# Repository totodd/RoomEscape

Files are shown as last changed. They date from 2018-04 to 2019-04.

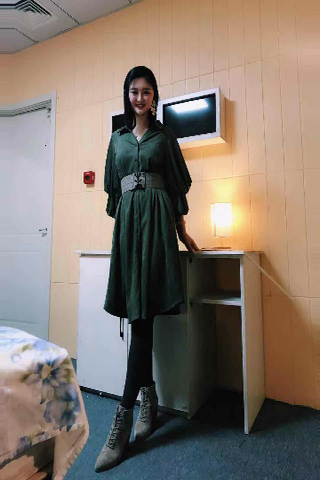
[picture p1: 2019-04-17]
module/Daniel/newPhone/色盲1/72.bmp

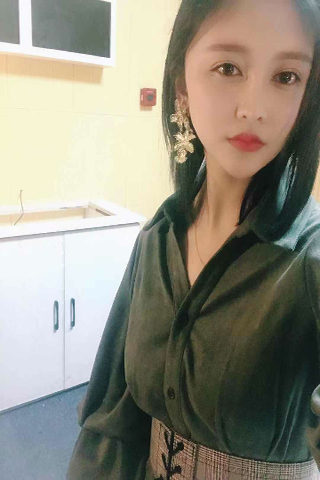
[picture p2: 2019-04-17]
module/Daniel/newPhone/色盲1/73.bmp

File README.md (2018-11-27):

# RoomEscape
room escape functions

[脉搏模块]
input:

inner connections:
  black: GND
  blue: input = LOW
  yellow: no display if LOW

[5分钟倒计时模块]

input:
  1. signal
  2. GND
  -. button
  3. power cable

functions:
    [initial:]
      all displaying zero
    [action:]
      if(signal || button)
        counter start from 5 mins

output:
  1. signal: HIGH when counting is over
  2. GND

inner connections:
  1. black: GND
  2. green: start signal = LOW
  3. yellow: reset signal = LOW
  4. red: 5V output
  5. white: signal when count down = LOW

[指纹模块]
input:
  -. button
  1. power cable

functions:
  [initial: ]
    if(fingerprint saved) scanning fingerprint
    else waiting for saving fingerprint
  [action:]
    if(button)
      clean all saved fingerprint, start waiting

    when setting fingerPrint:
      scan the fingerprint twice, when no light is flashing, setting is successful.
        (can only save one fingerprint)

output:
  1. signal = HIGH
  2. GND

[IC卡单卡模块]
input:

output:
  1. output signal = HIGH
  2. 5v vin
  3. GND
  4. GND
  5. SDA
  6. SCL

[IC总控]
input:
  1. power cable
  -. switch
  -. button

functions:
  - press button to add connected devices
  - pull switch to choose sequence mode or all-in mode

output:
  1. NOUT signal = LOW
  2. GND
  3. --
  4. GND
  5. GND
  6. OUT signal = HIGH

[电子琴]
input:

[抖音10s模块]
input:
  -. button
  1. power cable 12v
  2.

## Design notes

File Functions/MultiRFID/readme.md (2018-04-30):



 * Typical pin layout used:
 * -----------------------------------------------------------------------------------------
 *             MFRC522      Arduino       Arduino   Arduino    Arduino          Arduino
 *             Reader/PCD   Uno/101       Mega      Nano v3    Leonardo/Micro   Pro Micro
 * Signal      Pin          Pin           Pin       Pin        Pin              Pin
 * -----------------------------------------------------------------------------------------
 * RST/Reset   RST          9             5         D9         RESET/ICSP-5     RST
 * SPI SS 1    SDA(SS)      ** custom, take a unused pin, only HIGH/LOW required **
 * SPI SS 2    SDA(SS)      ** custom, take a unused pin, only HIGH/LOW required **
 * SPI MOSI    MOSI         11 / ICSP-4   51        D11        ICSP-4           16
 * SPI MISO    MISO         12 / ICSP-1   50        D12        ICSP-1           14
 * SPI SCK     SCK          13 / ICSP-3   52        D13        ICSP-3           15

in this application

Pin arrangement:

SS1 -> Pin 10
SS2 -> Pin 8
indicater1 -> Pin 2
indicater2 -> Pin 3
output -> Pin 4
reset -> Pin 5

variables:

NR_OF_READERS 	-> number of readers 
ssPins 			-> reader list 				
targetSequence 	-> the truth sequence of tapping readers
passAction() 	-> action after getting correct sequence
failAction() 	-> action after getting wrong sequence

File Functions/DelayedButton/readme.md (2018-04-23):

This foundamental function is used to design a delayed button input so that after a required time pressed, a control signal will be sent to control external devices, such as: Control lights on/off.  Locker open/close.

parameters declearation:

      Input:
      
            button :         Button Input Signal     
            Reset:           Highest external control
            
      Output:
      
            OutputSignal:    Output Controled signal (connect to LED or Locker or Relay)
            CurrentState:    Current state indicator, HIGH means WORKING, LOW means IDEL
            
      Variables:
        
            debounceDelay:    The amount of time to delay (second)

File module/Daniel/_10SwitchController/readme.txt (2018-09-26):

10 switches module

features:

reset pin

when pin match, output a high signal

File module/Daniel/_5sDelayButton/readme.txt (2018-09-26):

This is the 5 seconds delayed button, when button is pressed 5 seconds, will output a high signal

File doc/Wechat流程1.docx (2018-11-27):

流程:

遥控器：只连接主控，主控连接其他所有继电器/sensor

玩家被指引进黑暗房间，NPC触发一个视频（A1）【暂不开发】。视频播放后，照明灯亮起（A4）【有一个继电器模块管所有照明灯，暂定手动开所有】。NPC进入房间开场白。并指引玩家进入各个房间（A2）【一个遥控器，上面有十个按钮，分别对应五个门的上锁/解锁。继电器模块，逻辑模块，主控】，一切妥当后，NPC触发开启童谣模式（A3）【一个遥控器，控制开始播放，播放时，按照顺序播放闪电和童谣。音频模块，闪电灯模块，主控】并伴随闪电。第一次闪电后房间停电（A4）【继电器模块，主控】，断开房间1-8的照明，1-3的门。无线电通话应答器播放语音（A5）【由主控发起信号决定播放音频，音频模块，主控】，玩家可以使用手摇发电机（A4）【手摇发电机，继电器模块，测量模块，主控】，恢复电力。

以下为并行：（*）

*玩家可以在酒窖内找到3瓶酒放置正确位置（A6）【3点IC触控】，伸出推杆逃生。【电机模块】

*大厅玩家可以按住地图上1点，开启灯。（A7）【单点延时按钮模块】

*大厅玩家在日历上按住2点，开灯2（A7）【双点延时按钮模块】

*大厅玩家放置正确物品，开灯3（A7）【单点IC触控】

*大厅玩家按照琴谱弹奏，开灯3。 得到钥匙1（A7）【撞击模块，顺序模块】

*画室玩家放置正确物品开锁（A8）【ic触控，顺序模块】，玩家为4个物品挑选颜色（A8）【旋钮顺序开关】，开锁【电机模块】。得要钥匙2

*娱乐室玩家可以摆放3点飞镖（A9）【磁力模块】和6点的台球（A9）【红外模块】，得到钥匙3【电机模块】

在此期间内，NPC可以进入房间内，遥控断掉房间内1-8照明灯，亮起1-4警示灯（A4）。并播放一段音频（A3）。NPC走后，可以恢复照明至原来的效果（A4），并停止播放音频（A3）。

玩家收集4把钥匙以后，同时插进钥匙孔【四点金属感应模块】，NPC会收到警报（A10）【无线警报模块】。引导玩家进入下一房间。

以下为多选1：（不冲突）

*玩家可以通过输入一个切断电源的密码（A11）【小键盘密码模块 主控】，切断房间内灯源、门，同时亮起警示灯（A4.A3）【灯光模块】，同时开锁，NPC进入与玩家互动。10min后开门。

*NPC主动进入房间，进入蓝色字体模式（A3.A4）【灯光模块】，玩家需要找到枪和子弹，组装后，用枪射杀NPC（A12）【暂定玩具枪】。NPC死的时候帮助玩家开门（A2）

*NPC主动帮玩家开门（A2）

总价：16500， 如果加蓝灯效果（记录游戏状态，加1500）.

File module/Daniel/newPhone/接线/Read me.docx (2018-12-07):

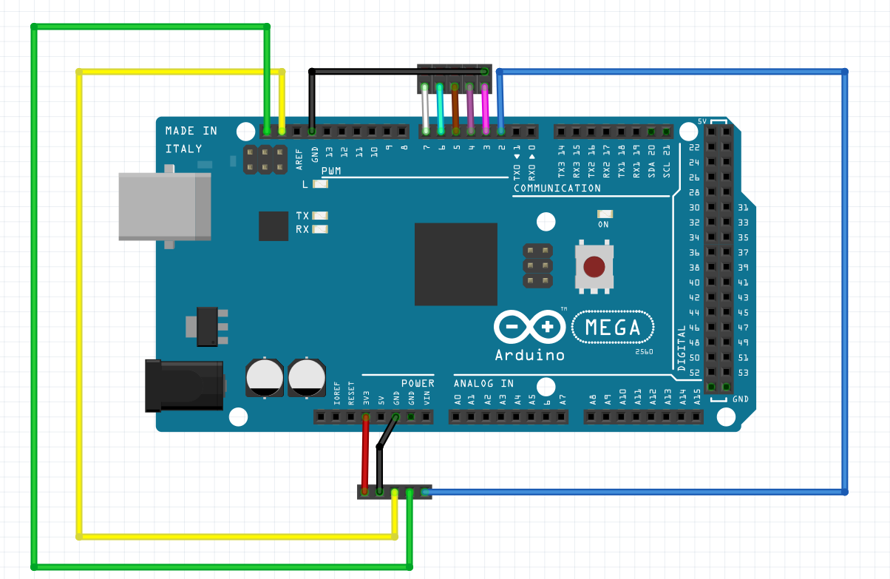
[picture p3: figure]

接线图下方的五条线，接好之后直接连接屏幕

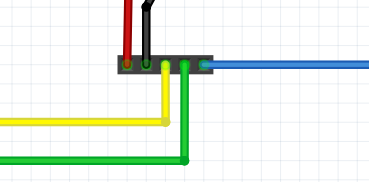
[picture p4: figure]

上方的：

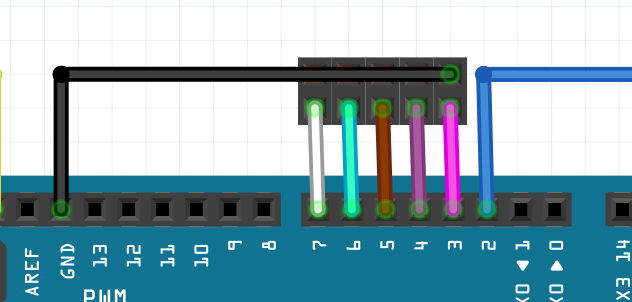
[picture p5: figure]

pin3： 定义为 INPUT，当A2的第四个音频播放完毕之后，输出HIGH到这里

pin4： 定义为 INPUT，当电话打完之后（电话音频播放完之后），输出HIGH到这里 （这个可以不用）

pin5： 定义为 OUTPUT， 连接MP3，这个输出HIGH的时候，播放电话音频文件

pin6： 定义为 OUTPUT， 连接MP3，这个输出HIGH的时候，播放开机音频文件

pin7： 定义为 OUTPUT， 连接MP3,这个输入HIGH的时候,播放电话来电响铃音频文件

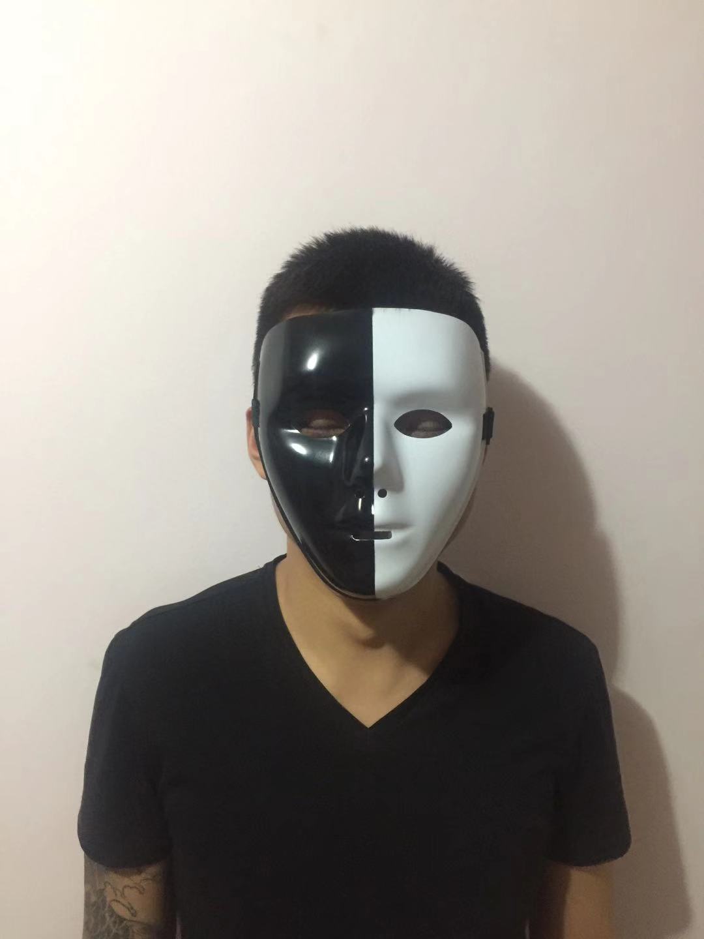
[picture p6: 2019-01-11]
module/faceRecog/15871544867203_.pic.jpg

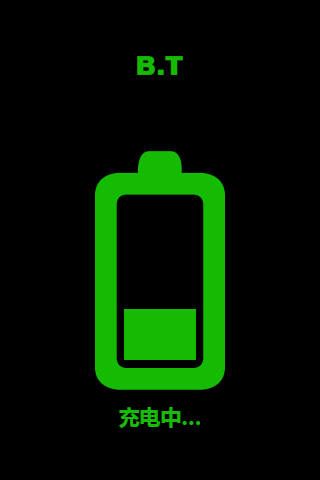
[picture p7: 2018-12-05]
module/Daniel/newPhone/色盲1/充电中1.bmp

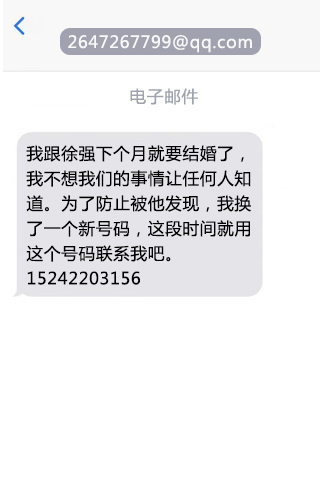
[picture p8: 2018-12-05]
module/Daniel/newPhone/色盲1/邮件界面.bmp

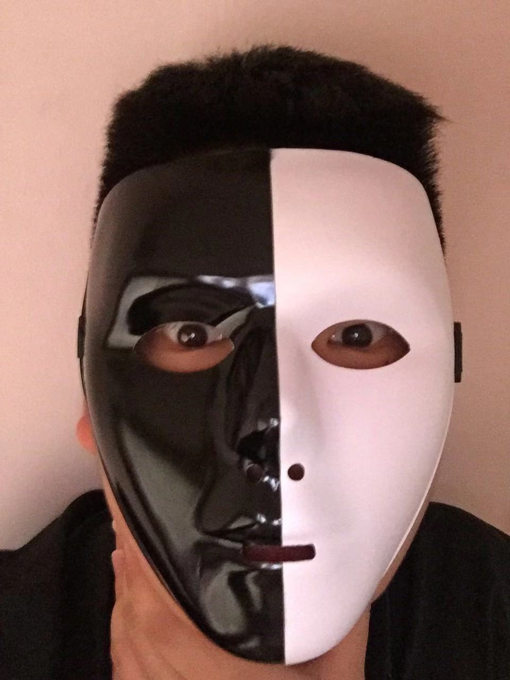
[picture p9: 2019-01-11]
module/faceRecog/15721544851673_.pic.jpg

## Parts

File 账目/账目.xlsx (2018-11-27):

 | 密室项目账单
 | 日期 | 名称 | 价格 | 总价 | 10777.49
 | 8.28 | 第一批材料 | 2568.34
 | 8.28 | 喷锡板 | 178 | 剩余 | 4222.51
 | 8.29 | MP3 解码 | 119.38
 | 8.29 | 对插线 | 159.8
 | 不记得了 | 衣服 | 500
 | 9.21 | Jaycar 电焊材料 | 122.75
 | 9.21 | bunnings 电焊 | 113.1
 | 9.26 | Jaycar | 149.75
 | 9.27 | Jaycar box | 105.5
 | 9.27 | bunnings 电钻 | 419.35
 | 9.27 | 第二批材料 | 739.97
 | 9.27 | MP5 | 283
 | 9.27 | vLCD | 239
 | 9.29 | 运费 | 152
 | 10.02 | 吃饭 | 370
 | 10.01 | 吃饭 | 197.5
 | 10.4 | PCB | 330
 | 不记得了 | Jaycar James | 155
 | 10.09 | tf卡 | 80
 | 10.09 | 话筒耳机 | 18
 | 10.09 | 开关 | 64
 | 10.11 | 第三批材料 | 313.2
 | 10.11 | arduino拓展板 | 61
 | 10.12 | 电线 | 32
 | 10.17 | Jaycar 盒子 | 165.25
 | 10.11 | Element14 | 157.85
 | 10.15 | Jaycar | 66.75
 | 10.12 | Jaycar 盒子 | 175
 | 10.16 | Kmart | 50
 | 10.15 | 运费 | 181
toto | 10.28 | pcb | 143
toto | 10.28 | 淘宝材料 | 12
toto | 10.28 | 淘宝材料 | 376
toto | 10.28 | 淘宝材料 | 63
toto | 10.28 | 淘宝材料 | 600
toto | 10.28 | 淘宝材料 | 194
toto | 10.28 | 淘宝材料 | 30
toto | 10.28 | 琴 | 311
toto | 10.28 | 计时 | 160
toto | 10.28 | 焊接工具 | 154
toto | 11.1 | 淘宝材料 | 214
toto | 11.1 | pcb | 188
toto | 11.1 | xh2.54 wire | 22
toto | 11.1 | 电烙铁 | 44

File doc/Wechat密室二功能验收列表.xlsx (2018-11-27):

基本模块编号 | 乙方提供 （数量待定） | 说明（要求与功能）
1 | 主控（顺序模块） | 用于连接不同模块，控制模块协同工作， 来完成特定功能，提供可手持遥控器
2 | 数码管计时器模块 | 5min倒计时
3 | 继电器模块 | 控制铁球落下，电磁门等设备
4 | 小键盘密码模块 | 输入密码控制控门继电器模块
5 | 指纹识别模块 | 识别甲方提供的指纹道具，触发 电子锁模块开锁
6 | 电子锁模块 | 有线，用于所有需要开锁的设备逻辑
7 | 虚拟机模块 | 用户输入制定日期，播放对应视频
8 | 10秒计时模块 | 模式一：演示模式，拍一下是0，再拍一下 是10. 模式二：玩家模式，拍一下是0，再拍一下 数到几就是几
9 | 四点IC模块 | IC卡接触读卡器之后触发
10 | 10点switch模块 | 十个switch分别有正负两种状态，其中四个拨到负状态，触发
 |  | 报价：16500

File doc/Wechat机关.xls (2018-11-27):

编号 | 名称 | 描述 | 备注
A1 | 进门视频 | NPC触发视频
A2 | 黑白牛马 | 4点IC卡，同时放置后触发开锁，播放音频
A3 | 对联机关 | 7点IC卡，同时放置开锁。音频。
A4 | 生辰八字 | 22位按钮，输入8位密码，播放音频，再输入8位密码，播放音频，开锁。
A5 | 拍婚照 | AR感应/IC卡+重力感应，识别后，闪光灯闪一下，开锁，音频。
A6 | 牌位 | 2点IC卡，开锁。

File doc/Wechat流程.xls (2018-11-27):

编号 | 名称 | 描述 | b备注
A1 | 无线接收 | 可以无线接受控制电话的响铃（第一次），2个房间门的通断。 | 一共4个音响，房间内的提示音；走廊的音效；电话；手机；
A2 | 电话机关 | 无线遥控响铃，摘机后播放语音1。按8888，A3播放不同画面。A4触发后，响铃摘机播放语音2.语音2播放完成后，房间1门打开（A1）。A3播放完视频3之后，响铃，播放语音3.通过拨打数字串，播放外卖语音，正确触发后，且房间1门关闭（需检测）播放视频4（A3），A3播放完录像4以后，响铃，播放录音4.拨打手机号，走廊音响响起，走廊音效和电话音效同步。 | 语音1234，可以通过按钮1234来重播。
A3 | 双视频 | 初始为黑屏待机画面，A2完成8888后，播放两个不同画面。A4完成后，播放两个画面。A5每个密码完成后会得到对应视频，其中走廊监控器为实时监控，两个画面都得到后，且房间1门关闭（需检测且吸合）会播放视频1.视频1播放完毕后按钮1触发，可以重播视频1，播放完毕回到红字状态。A6触发后，播放录像2，按钮2可以重播视频2，播放回到红字，且房间1门打开。A7触发接通电源1后，播放视频3，播放完毕后，房间1门开（A1）。按钮3可以重播录像3，完毕回到红字。A2外卖完毕后，且门关，播放视频4.播完后，A2电话响，视频播放视频5.A2触发电话号后，同步播放视频6，视频6结束后，断掉所有电源。 | 带音效，设置在走廊
A4 | 保险箱 | 小键盘输入7位密码，开锁。
A5 | 录像台 | 按下按钮，升起推杆。同时播放音频，用大键盘输入走廊和房间监控器编号，按钮可切换输入行，并可以重复触发语音。成功输入后。A3可以获得对应的视频，其中一个是实时监控。两个都成功输入后，播放语音。 | 走廊监控器编号 房间监控器编号
A6 | 5灯开关 | 酒店5灯开关，5个按顺序按下后，开锁。A3播放录像2.
A7 | 断电机关 | 磁力感应1（干簧管按钮）断掉电源1（继电器）播放音频。IC卡感应后，且房间1门关闭（需检测且吸合）后，接通电源1.A3视频6播放完毕后，断掉电源2.磁力感应2（再此之前不能触发），触发后开门。
A8 | 人脸识别 | A7断电之后，才能触发，但需要提前供电。触发后开锁。
A9 | 手机 | 游戏开始时，一直显示为充电中，A2播放完录音4后，开启开机步骤，且开机后立即进来一个电话，接听后，播放一段语音。语语音播放完毕后，房间内播放提示音。完毕后，有4个功能可以使用，短信，图片，邮件。点开邮件并列3张图片，输入3位密码，可以看到邮件内容。点开短信会看到一个短信。点开图片会看到几张图片。

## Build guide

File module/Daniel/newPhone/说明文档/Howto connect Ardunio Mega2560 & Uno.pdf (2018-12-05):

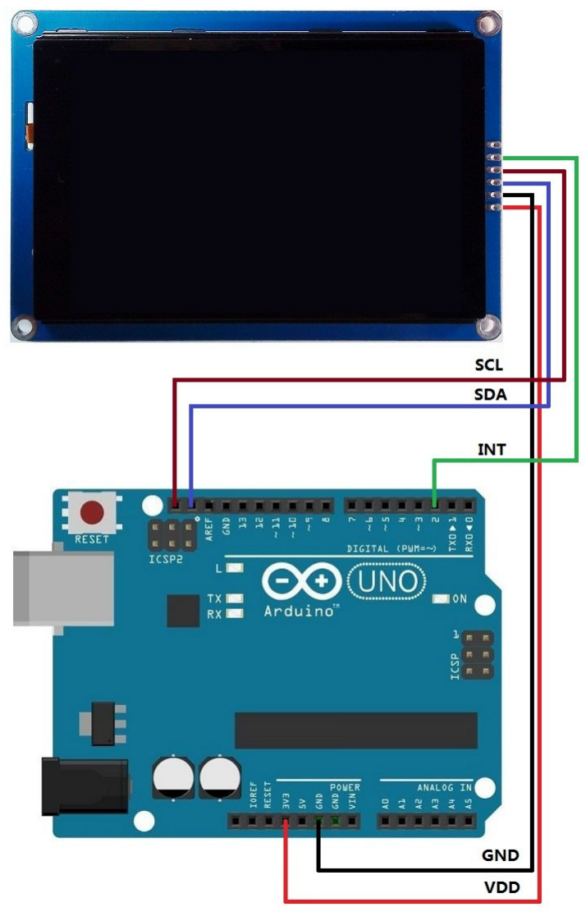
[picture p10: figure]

1. Connect to the Ardunio Uno board.

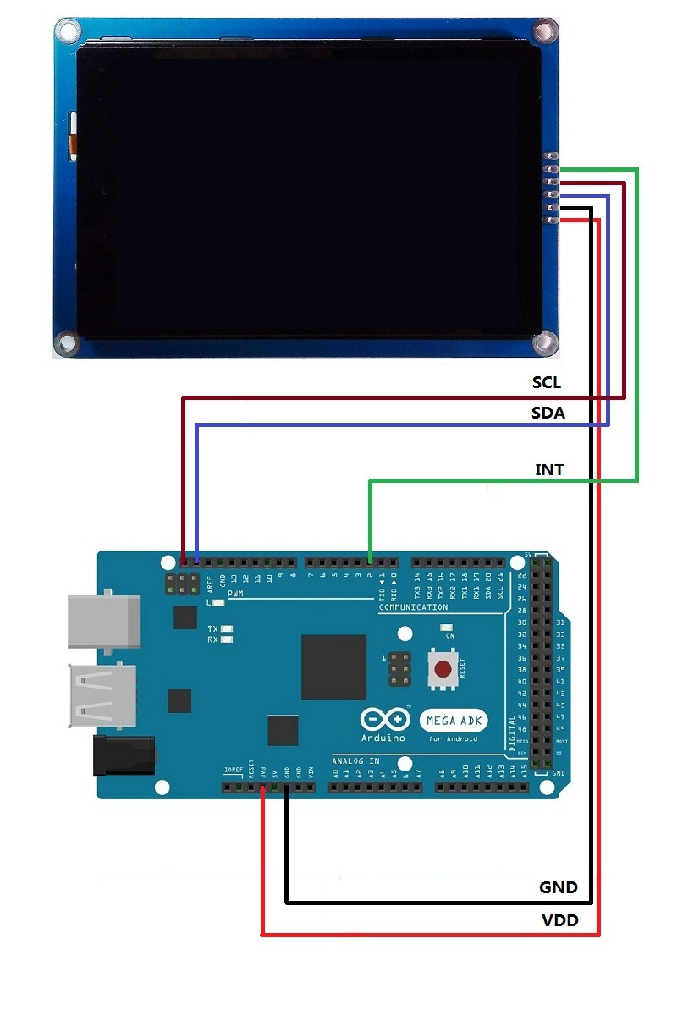
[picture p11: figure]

2. Connect to the Ardunio Mega2560 board.

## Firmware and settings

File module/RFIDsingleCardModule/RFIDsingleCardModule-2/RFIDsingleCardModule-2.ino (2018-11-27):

/**

   Typical pin layout used:
   -----------------------------------------------------------------------------------------
               MFRC522      Arduino       Arduino   Arduino    Arduino          Arduino
               Reader/PCD   Uno/101       Mega      Nano v3    Leonardo/Micro   Pro Micro
   Signal      Pin          Pin           Pin       Pin        Pin              Pin
   -----------------------------------------------------------------------------------------
   RST/Reset   RST          9                      D9
   SPI SS 1    SDA(SS)      ** custom, take a unused pin, only HIGH/LOW required *
   SPI SS 2    SDA(SS)      ** custom, take a unused pin, only HIGH/LOW required *
   SPI MOSI    MOSI         11 / ICSP-4   51        D11        ICSP-4           16
   SPI MISO    MISO         12 / ICSP-1   50        D12        ICSP-1           14
   SPI SCK     SCK          13 / ICSP-3   52        D13        ICSP-3           15

*/

// change SDA SCL pin to active pin
//

#include <EEPROM.h>

#include <Wire.h>
#include <SPI.h>
#include <MFRC522.h>

#define RST_PIN         9          // Configurable, see typical pin layout above

//each SS_x_PIN variable indicates the unique SS pin for another RFID reader
#define SS_PIN        2         // Configurable, take a unused pin, only HIGH/LOW required, must be diffrent to SS 2
#define MODE_SWITCH 4

#define MAX_NR_OF_CARDS  10
// #define ENABLE_PIN A4
#define output 7
#define outputIndicator 6
byte count = 0;

MFRC522 mfrc522(SS_PIN, RST_PIN);   // Create MFRC522 instance.

String savedKey = "cardstor";
boolean cardPresentState = false;
boolean settingMode = false;
String read_rfid;
String cardStored[MAX_NR_OF_CARDS];
String tempStored[MAX_NR_OF_CARDS];
int storedCount = 0;
int scanCount = 0;

int ledState = LOW;
boolean isBlinking = false;

const String masterCardIDs[] ={"8a677b89","95adf17","96a2e11","4973ea17","8949c18","899cec17","59c22b17","a9682b11","49e83c11","9c3e917"};

unsigned long previousMillis = 0;        // will store last time LED was updated
unsigned long previousMillisCard = 0;
// constants won't change:
const long interval = 500;
const long flashinterval = 80;
const long settingInterval = 3000;
/**d
   Initialize.
*/
void setup() {
  Serial.begin(9600); // Initialize serial communications with the PC
  while (!Serial);    // Do nothing if no serial port is opened (added for Arduinos based on ATMEGA32U4)

  pinMode(output, OUTPUT);
  pinMode(outputIndicator, OUTPUT);
  // pinMode(ENABLE_PIN, INPUT);
  pinMode(MODE_SWITCH, INPUT_PULLUP);
  digitalWrite(output, LOW);
  digitalWrite(outputIndicator, LOW);
  // autoSetAddr();


  readSavedInfoROM();


  SPI.begin();        // Init SPI bus
  mfrc522.PCD_Init();   // Initiate MFRC522
  mfrc522.PCD_DumpVersionToSerial();

}

// bool disable;
/**
   Main loop.
*/
void loop() {


    Serial.print("Setting mode: ");
    Serial.print(settingMode);
    Serial.print("  storedCount:");
    Serial.print(storedCount);
    Serial.print("  cardStored 0: ");

    Serial.print(cardStored[0]);
    Serial.print(" card: ");
    Serial.print(mfrc522.uid.size);
    Serial.print(" card scanned id:");
    Serial.print(read_rfid);
    Serial.print(" scanned #:");
    Serial.println(scanCount);



    if (settingMode && storedCount == 0) digitalWrite(outputIndicator, HIGH);
    if (!settingMode) digitalWrite(outputIndicator, LOW);


    if (settingMode) {
      // if (!isBlinking) blinkLED();
      if (((millis() - previousMillisCard) >= settingInterval) && (storedCount > 0)) {
        write_StringEE(MAX_NR_OF_CARDS, savedKey);
        EEPROM.write((MAX_NR_OF_CARDS + 1) * 8 + 1, storedCount);
        settingMode = false;
      }

      if (mfrc522.PICC_IsNewCardPresent() && mfrc522.PICC_ReadCardSerial()) {
        Serial.println("card sensed");


        cardPresentState = true;
        dump_byte_array(mfrc522.uid.uidByte, mfrc522.uid.size);
        Serial.println(isMaster(read_rfid));

        if (!isMaster(read_rfid)) {
          Serial.println("not master");

          if (!inArray(read_rfid, cardStored)) {
            cardStored[storedCount] = read_rfid;

            write_StringEE(storedCount, read_rfid);
            // EEPROM.write(storedCount, read_rfid);
            storedCount++;
            flashLED();
            previousMillisCard = millis();

          }
        }
      }
    }
    if (!settingMode) {
      // if (isBlinking) stopBlink();
      if (mfrc522.PICC_IsNewCardPresent() && mfrc522.PICC_ReadCardSerial()) {

        cardPresentState = true;
        dump_byte_array(mfrc522.uid.uidByte, mfrc522.uid.size);
        //mastercard scanned
        if (isMaster(read_rfid)) {
          storedCount = 0;
          scanCount = 0;
          for (int n = 0; n < MAX_NR_OF_CARDS; n++) {
            cardStored[n] = "";
          }
          read_rfid = "";
          for (int n = 0; n < EEPROM.length(); n++) {
            EEPROM.write(n, 0);
          }
          settingMode = true;
          // setup();
          digitalWrite(output, LOW);
          digitalWrite(outputIndicator, LOW);
        }

        // check pass condition
        if (!inArray(read_rfid, tempStored) && inArray(read_rfid, cardStored)) {
          tempStored[scanCount] = read_rfid;
          scanCount++;
        }

        //  else if (!mfrc522.PICC_ReadCardSerial()) {
        //   cardPresentState = false;
        //   waitAction();
        // }
      }
      if(scanCount == storedCount && storedCount != 0){
            if(isPassed()) passAction();
            else {
              scanCount = 0;
              for(int n = 0; n < storedCount; n++){
                tempStored[n] = "";
              }
            }
      }

      // Serial.println(cardPresentState);
//      delay(100);

    }

}

boolean isPassed() {
  for(int n = 0; n < storedCount; n++){
    if(tempStored[n] != cardStored[n]) return false;
  }
  return true;
}

void passAction() {
  digitalWrite(output, HIGH);
  digitalWrite(outputIndicator, HIGH);
//  delay(1500);
//  digitalWrite(output, LOW);
//  digitalWrite(outputIndicator, LOW);
  scanCount = 0;
  for(int n = 0; n < storedCount; n++){
    tempStored[n] = "";
  }
}

void waitAction() {
  digitalWrite(output, LOW);
  digitalWrite(outputIndicator, LOW);
  isBlinking = false;

}

void stopBlink() {
  digitalWrite(outputIndicator, LOW);
}

void flashLED() {
  for (int n = 0; n < 3; n++) {
    digitalWrite(outputIndicator, HIGH);
    delay(flashinterval);
    digitalWrite(outputIndicator, LOW);
    delay(flashinterval);
  }
}

void blinkLED() {
  isBlinking = true;
  unsigned long currentMillis = millis();

  if (currentMillis - previousMillis >= interval) {
    // save the last time you blinked the LED
    previousMillis = currentMillis;

    // if the LED is off turn it on and vice-versa:
    if (ledState == LOW) {
      ledState = HIGH;
    } else {
      ledState = LOW;
    }

    // set the LED with the ledState of the variable:
    digitalWrite(outputIndicator, ledState);
  }


}

boolean array_cmp(String *a, String *b, int len_a, int len_b) {
  int n;

  //if their lengths are different, return false
  if (len_a != len_b) return false;

  //test each element to be the same. if not, return false
  for (n = 0; n < len_a; n++) if (a[n] != b[n]) return false;

  //ok, if we have not returned yet, they are equal :)
  return true;
}

boolean inArray(String id, String * array) {
  for (int n = 0; n < storedCount; n++) {

    if (array[n] == id) {
      return true;
    }
  }
  return false;
}

void dump_byte_array(byte * buffer, byte bufferSize) {
  read_rfid = "";
  for (byte i = 0; i < bufferSize; i++) {
    read_rfid = read_rfid  + String(buffer[i], HEX);
  }
}

void requestEvent() {
  Wire.write(cardPresentState); // respond with message of 6 bytes
  // as expected by master
}

// void autoSetAddr() {
//   Serial.println ();
//   Serial.println ("I2C scanner. Scanning ...");
//   int myAddr = 1;
//   int maxAddr = 0;
//   Wire.begin();
//   for (byte i = 1; i < 30; i++)
//   {
//     Wire.beginTransmission (i);
//     if (Wire.endTransmission () == 0)
//     {
//       Serial.print ("Found address: ");
//       Serial.print (i, DEC);
//       Serial.print (" (0x");
//       Serial.print (i, HEX);
//       Serial.println (")");
//       count++;
//       if (i > maxAddr) maxAddr = i;
//     }// end of good response
//     delay (5);  // give devices time to recover
//   }
//   myAddr = maxAddr + 1;
//   // end of for loop
//   Serial.println ("Done.");
//   Serial.print ("Found ");
//   Serial.print (count, DEC);
//   Serial.println (" device(s).");
//
//
//   Serial.print ("my Addr is ");
//   Serial.println (myAddr);
//
//   Wire.begin(myAddr);                // join i2c bus with address #8
//   // Wire.onReceive(receiveEvent); // register event
//   Wire.onRequest(requestEvent); // register event
//
//
// }

void readSavedInfoROM() {
  // int cnt = 0;
  Serial.println("start reading rom");
  Serial.print("card saved?");
  Serial.println(read_StringEE(MAX_NR_OF_CARDS, 8));
  // card is saved in ROM
  if (read_StringEE(MAX_NR_OF_CARDS, 8) == savedKey) {
    settingMode = false;
    storedCount = EEPROM.read((MAX_NR_OF_CARDS + 1) * 8 + 1);
    Serial.print("cardCount from ROM: ");
    Serial.println(storedCount);

    Serial.print("cards saved: ");
    for (int n = 0; n < MAX_NR_OF_CARDS; n++) {
      cardStored[n] = read_StringEE(n, 8);//Read String starting a address 0 with given lenth of String
      Serial.println(cardStored[n]);
    }
  } else { //  card is not saved in ROM
    settingMode = true;
  }
}


bool write_StringEE(int Addr, String input)
{
  char cbuff[input.length() + 1]; //Finds length of string to make a buffer
  input.toCharArray(cbuff, input.length() + 1); //Converts String into character array
  return eeprom_write_string(Addr*8, cbuff); //Saves String
}

String read_StringEE(int Addr, int length)
{

  char cbuff[length + 1];
  boolean didget = eeprom_read_string(Addr * 8, cbuff, length + 1);

  String stemp(cbuff);
  if (didget) {
    Serial.print("got 1 from rom ");
    Serial.print(Addr);
    Serial.print("   ");
    Serial.println(stemp);
  }

  return stemp;

}
/*
  Test code for writing a String to the EEPROM and then reading it Back
  Written by Mario Avenoso, M-tech Creations
  4/10/16
*/

//http://ediy.com.my/index.php/tutorials/item/68-arduino-reading-and-writing-string-to-eeprom

const int EEPROM_MIN_ADDR = 0;
const int EEPROM_MAX_ADDR = 511;

// Returns true if the address is between the
// minimum and maximum allowed values, false otherwise.
//
// This function is used by the other, higher-level functions
// to prevent bugs and runtime errors due to invalid addresses.
boolean eeprom_is_addr_ok(int addr) {
  return ((addr >= EEPROM_MIN_ADDR) && (addr <= EEPROM_MAX_ADDR));
}


// Writes a sequence of bytes to eeprom starting at the specified address.
// Returns true if the whole array is successfully written.
// Returns false if the start or end addresses aren't between
// the minimum and maximum allowed values.
// When returning false, nothing gets written to eeprom.
boolean eeprom_write_bytes(int startAddr, const byte * array, int numBytes) {
  // counter
  int i;

  // both first byte and last byte addresses must fall within
  // the allowed range
  if (!eeprom_is_addr_ok(startAddr) || !eeprom_is_addr_ok(startAddr + numBytes)) {
    return false;
  }

  for (i = 0; i < numBytes; i++) {
    EEPROM.write(startAddr + i, array[i]);
  }

  return true;
}


// Writes a string starting at the specified address.
// Returns true if the whole string is successfully written.
// Returns false if the address of one or more bytes fall outside the allowed range.
// If false is returned, nothing gets written to the eeprom.
boolean eeprom_write_string(int addr, const char* string) {

  int numBytes; // actual number of bytes to be written

  //write the string contents plus the string terminator byte (0x00)
  numBytes = strlen(string) + 1;

  return eeprom_write_bytes(addr, (const byte*)string, numBytes);
}


// Reads a string starting from the specified address.
// Returns true if at least one byte (even only the string terminator one) is read.
// Returns false if the start address falls outside the allowed range or declare buffer size is zero.
//
// The reading might stop for several reasons:
// - no more space in the provided buffer
// - last eeprom address reached
// - string terminator byte (0x00) encountered.
boolean eeprom_read_string(int addr, char* buffer, int bufSize) {
  byte ch; // byte read from eeprom
  int bytesRead; // number of bytes read so far

  if (!eeprom_is_addr_ok(addr)) { // check start address
    return false;
  }

  if (bufSize == 0) { // how can we store bytes in an empty buffer ?
    return false;
  }

  // is there is room for the string terminator only, no reason to go further
  if (bufSize == 1) {
    buffer[0] = 0;
    return true;
  }

  bytesRead = 0; // initialize byte counter
  ch = EEPROM.read(addr + bytesRead); // read next byte from eeprom
  buffer[bytesRead] = ch; // store it into the user buffer
  bytesRead++; // increment byte counter

  // stop conditions:
  // - the character just read is the string terminator one (0x00)
  // - we have filled the user buffer
  // - we have reached the last eeprom address
  while ( (ch != 0x00) && (bytesRead < bufSize) && ((addr + bytesRead) <= EEPROM_MAX_ADDR) ) {
    // if no stop condition is met, read the next byte from eeprom
    ch = EEPROM.read(addr + bytesRead);
    buffer[bytesRead] = ch; // store it into the user buffer
    bytesRead++; // increment byte counter
  }

  // make sure the user buffer has a string terminator, (0x00) as its last byte
  if ((ch != 0x00) && (bytesRead >= 1)) {
    buffer[bytesRead - 1] = 0;
  }

  return true;
}

bool isMaster(String s){
  for (int i = 0; i < 10; i++) {
    if(s == masterCardIDs[i]) {
      Serial.println(s + "  " + masterCardIDs[i] + " " + "at index"+i);
      Serial.println(sizeof(masterCardIDs));
      return true;
    }
  }
  return false;
}

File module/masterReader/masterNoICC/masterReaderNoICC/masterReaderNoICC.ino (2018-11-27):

// Wire Master Writer
// by Nicholas Zambetti <http://www.zambetti.com>

// Demonstrates use of the Wire library
// Writes data to an I2C/TWI slave device
// Refer to the "Wire Slave Receiver" example for use with this

// Created 29 March 2006

// This example code is in the public domain.

#include <SPI.h>
#include <Wire.h>
#include <Adafruit_GFX.h>
#include <Adafruit_SSD1306.h>
#include <EEPROM.h>


#define ICPIN_1 2
#define ICPIN_2 3
#define ICPIN_3 4
#define ICPIN_4 5
#define ICPIN_5 6
#define ICPIN_6 7
#define ICPIN_7 8
#define ICPIN_8 9
#define ICPIN_9 10
#define ICPIN_10 11
// #define ICPIN_11 12
// #define ICPIN_12 13

#define MODE_SWITCH A2
#define BUTTON A1
#define output A0
#define ENABLE_PIN A3
#define IC_ENABLE 12
#define IC_RST 13

#define SEQUENCE_MODE 1
#define ALLIN_MODE 2

int ICpins[] = {ICPIN_1, ICPIN_2, ICPIN_3, ICPIN_4, ICPIN_5, ICPIN_6, ICPIN_7, ICPIN_8, ICPIN_9, ICPIN_10};

Adafruit_SSD1306 display;
#if (SSD1306_LCDHEIGHT != 32)
#error("Height incorrect, please fix Adafruit_SSD1306.h!");
#endif


#define MAX_NR_OF_SLAVES    12

int count;
int tapCount;
int slaveArray[MAX_NR_OF_SLAVES];
int countAddr = 1;
int savedAddr = 0;

int targetSeq[MAX_NR_OF_SLAVES];

bool sequenceResult = true;

int pinIndex = 0;
int seqCount = 0;
int cardCount = 0;
int toCheckPins[MAX_NR_OF_SLAVES];
int originPins[MAX_NR_OF_SLAVES];
int pinsStatus[MAX_NR_OF_SLAVES];

bool enable;

void setup() {
  Serial.begin (9600);
  tapCount = 0;

  initDisplay();
  // scanSlaves();

  if(EEPROM.read(savedAddr) == 1){
    count = EEPROM.read(countAddr);
  }else{
    count = 1;
  }

  pinMode(ENABLE_PIN, INPUT_PULLUP);
  pinMode(BUTTON, INPUT);
  pinMode(output, OUTPUT);
  pinMode(MODE_SWITCH, INPUT);
  pinMode(IC_ENABLE, OUTPUT);
  pinMode(IC_RST, OUTPUT);
  digitalWrite(output, LOW);
  digitalWrite(IC_RST, LOW);
  // digitalWrite(IC_RST, HIGH); // no reset


  for (int i = 0; i < MAX_NR_OF_SLAVES; i++) {
    pinMode(ICpins[i], INPUT);
  }


  for (int index = 0; index < count; index++) {
    /* code */
    targetSeq[index] = index; //target seq = 0 1 2 3 4
    toCheckPins[index] = index + 2; // pin set 2 3 4 5 6
    originPins[index] = index + 2;
  }
}

int reading[MAX_NR_OF_SLAVES];
int sequence[MAX_NR_OF_SLAVES];

String mode = "seq";

//------------------loop ----------------
void loop() {

  digitalWrite(IC_RST, HIGH);

  enable = digitalRead(ENABLE_PIN);
  boolean buttonPressed = digitalRead(BUTTON);
  // digitalWrite(IC_RST, HIGH); // no reset
  if(!enable) {
    Serial.println("disable");
    digitalWrite(IC_ENABLE, LOW);
  }
  if(enable) {
    digitalWrite(IC_ENABLE, HIGH);
    if(buttonPressed){
      if(count < 12)count++;
      else count = 1;
      EEPROM.write(countAddr, count);
      EEPROM.write(savedAddr, 1);
    }


    if(digitalRead(MODE_SWITCH)) mode = "seq";
    else mode = "all";

    if (mode == "seq") sequenceModeProcess();
    else allinModeProcess();

    showTextNumber("Dev #: ", count, "Mode: ", mode);


    delay(50);
  }
}






//--------------functions ------------

void resetProgram(){
  digitalWrite(output, LOW);
  setup();
}


void copy(int* src, int* dst, int len) {
    memcpy(dst, src, sizeof(src[0])*len);
}


boolean check_condition(int *arr) {
  for (int n = 0; n < count; n++) {

    if (arr[n] != 1) {
      return false;
    }
  }
  return true;
}

void allinModeProcess() {
  for (int i = 0; i < count; i++) {
    int input = digitalRead(ICpins[i]);
    reading[i] = input;
  }

  if (check_condition(reading)) {
    passAction();
  }
}

void removePin(int i, int array[MAX_NR_OF_SLAVES]){
  int tmp[MAX_NR_OF_SLAVES];
  int cnt = 0;
  for(int ind = 0; ind < (count - tapCount); ind++){
    if(i != array[ind]){
      tmp[cnt] = array[ind];
      cnt++;
    }
  }
  copy(tmp, array, MAX_NR_OF_SLAVES);
}

void sequenceModeProcess() {
  // digitalWrite(IC_RST, LOW);
  Serial.print("seqCount: ");
  Serial.print(seqCount);
  Serial.print("   toCheckPins: ");
  for (int i = 0; i < count; i++) {
    /* code */
    Serial.print(toCheckPins[i]);
  }
  // Serial.println();

  Serial.print("   pinsStatus: ");
  for (int i = 0; i < count; i++) {
    /* code */
    Serial.print(pinsStatus[i]);
  }
  // Serial.println();

  Serial.print("   pin 2 reading: ");
  Serial.print(digitalRead(toCheckPins[0]));
  Serial.print("   cardCount ");
  Serial.println(cardCount);
  int unchecked = 0;
  int checked = 1;

  if(cardCount >= count) {
    if(sequenceResult) {
      Serial.println("right seq");
      passAction();
    }
    else{ // wrong sequence
      Serial.println("wrong seq");

      if(checkEmpty(toCheckPins)){
        delay(1500);
        if(checkEmpty(toCheckPins)){ // if cards removed
          rstReaders();
          sequenceResult = true;

          seqCount = 0; // reset checking sequence
          cardCount = 0;
          for (int i = 0; i < count; i++) {
            /* code */
            pinsStatus[i] = 0;
          }
        }
      }
    }
  }
  for (int pinIndex = 0; pinIndex < count; pinIndex++) {
    if(pinsStatus[pinIndex]== unchecked && digitalRead(toCheckPins[pinIndex]) == 1){ // if get reading at pinindex
      cardCount++;
      pinsStatus[pinIndex] = checked;

      if(targetSeq[seqCount] == (toCheckPins[pinIndex]-2)){ // if pin at pinindex is in sequence
        seqCount++; // move on checking sequence
      }else{ // if pin is in wrong sequence
        sequenceResult = false;
        Serial.println("already wrong");
        // break;

      }
    }
  }

}

void passAction() {
  digitalWrite(output, HIGH);
}

void scanSlaves() {
  Serial.println ();
  Serial.println ("I2C scanner. Scanning ...");
  Wire.begin();
  showText("Scanning..");

  for (byte i = 1; i < MAX_NR_OF_SLAVES; i++)
  {

    Wire.beginTransmission (i);
    if (Wire.endTransmission () == 0)
    {
      Serial.print ("Found address: ");
      Serial.print (i, DEC);
      Serial.print (" (0x");
      Serial.print (i, HEX);
      Serial.println (")");
      slaveArray[count] = i;
      count++;

    } // end of good response
    delay (5);  // give devices time to recover
  } // end of for loop
  Serial.println ("Done.");
  Serial.print ("Found ");
  Serial.print (count, DEC);
  Serial.println (" device(s).");
}

void initDisplay() {
  // by default, we'll generate the high voltage from the 3.3v line internally! (neat!)
  display.begin(SSD1306_SWITCHCAPVCC, 0x3C);  // initialize with the I2C addr 0x3C (for the 128x32)
  // init done
  display.clearDisplay();
  display.setRotation(0);
  display.dim(0);
}


void showTextNumber(String s, int num, String s2, String s3) {
  // display.setFont(&FreeMonoBold12pt7b);  // Set a custom font
  char string[10];

  display.setTextSize(2);
  display.setTextColor(WHITE);
  display.setTextWrap(true);
  dtostrf(num, 3, 0, string);

  display.setCursor(0, 0);
  display.clearDisplay();
  display.print(s);
  display.println(string);
  display.print(s2);
  display.println(s3);
  display.display();
  // delay(1);
}
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

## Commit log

2018-04-22 Source Code for delayed button
2018-04-22 explanation of delayed button
2018-09-23 pcb sketch
    [RFID sketch_contour.gm1, RFID sketch_copperBottom.gbl, RFID sketch_copperTop.gtl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]
2018-09-26 PCB settled
    PCB settled
    [RFID sketch_contour.gm1, RFID sketch_copperBottom.gbl, RFID sketch_copperTop.gtl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]
2018-09-26 Upload Daniel‘s part
    Upload Daniel‘s part
2018-09-28 gerber file
    [Untitled Sketch 2.fzz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]
2018-09-28 can't use same power source for IC module and IC master
    [Untitled Sketch 2.fzz]
2018-10-01 pcb UPDATE
    [miniController.fzz]
2018-10-01 miniController update
    [miniController.fzz]
2018-10-05 PCB export
    [miniController2_contour.gm1, miniController2_copperBottom.gbl, miniController2_copperTop.gtl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]
2018-10-05 Revert "gerber file"
    This reverts commit 90114089b257538f2a83a9807d4518605e39c09b.
    [Untitled Sketch 2_contour.gm1, Untitled Sketch 2_copperBottom.gbl, Untitled Sketch 2_copperTop.gtl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]
2018-10-28 master and PCBs
    [RFID sketch 2.0_contour.gm1, RFID sketch 2.0_copperBottom.gbl, RFID sketch 2.0_copperTop.gtl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]
2018-11-27 pin pad update
2018-12-07 暗杀手机
    更新了功能，以及连线图
    [接线.fzz]
2018-12-24 face recog
    [Wechat档案.xls]
